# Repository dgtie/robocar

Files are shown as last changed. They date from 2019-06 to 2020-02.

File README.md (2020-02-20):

# robocar
stm32f103c8t6

## Setup SD card
[Download Raspberry Pi Zero WH image](https://polyuit-my.sharepoint.com/:u:/g/personal/ensylam_polyu_edu_hk/EfPde7mzcR5NiaSuWeZethsBixlZN2U6amez3VQq-VrPfw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)\
Write image to SD card. (using balenaEtcher or otherwise)\
Disable SD card reader (through device manager) and then enable it again.\
Modify the following files (in "boot" drive):

- wpa_supplicant.conf (ssid, password)
- hostname & hosts (raspberrypi -> newHostname, eg 19xxxxxxd)

Put SD card to raspberry pi zero and boot.

## SSH to raspberry pi
launch command prompt\
enter "ping -4 19xxxxxxd.local" to check ip address (Bonjour Print Service)\
SSH via putty or otherwise. (ssh pi@19xxxxxxd.local) (pwd = raspberry)

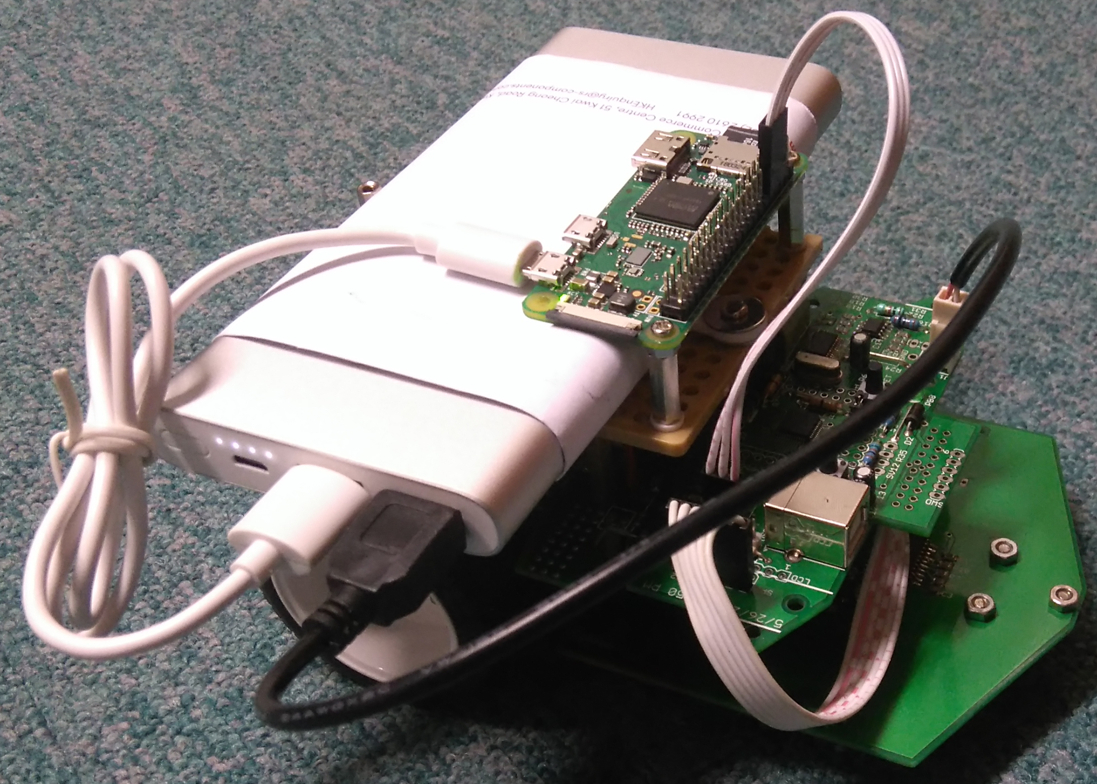
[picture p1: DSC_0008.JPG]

(https://youtu.be/ckLhx3viHC8)

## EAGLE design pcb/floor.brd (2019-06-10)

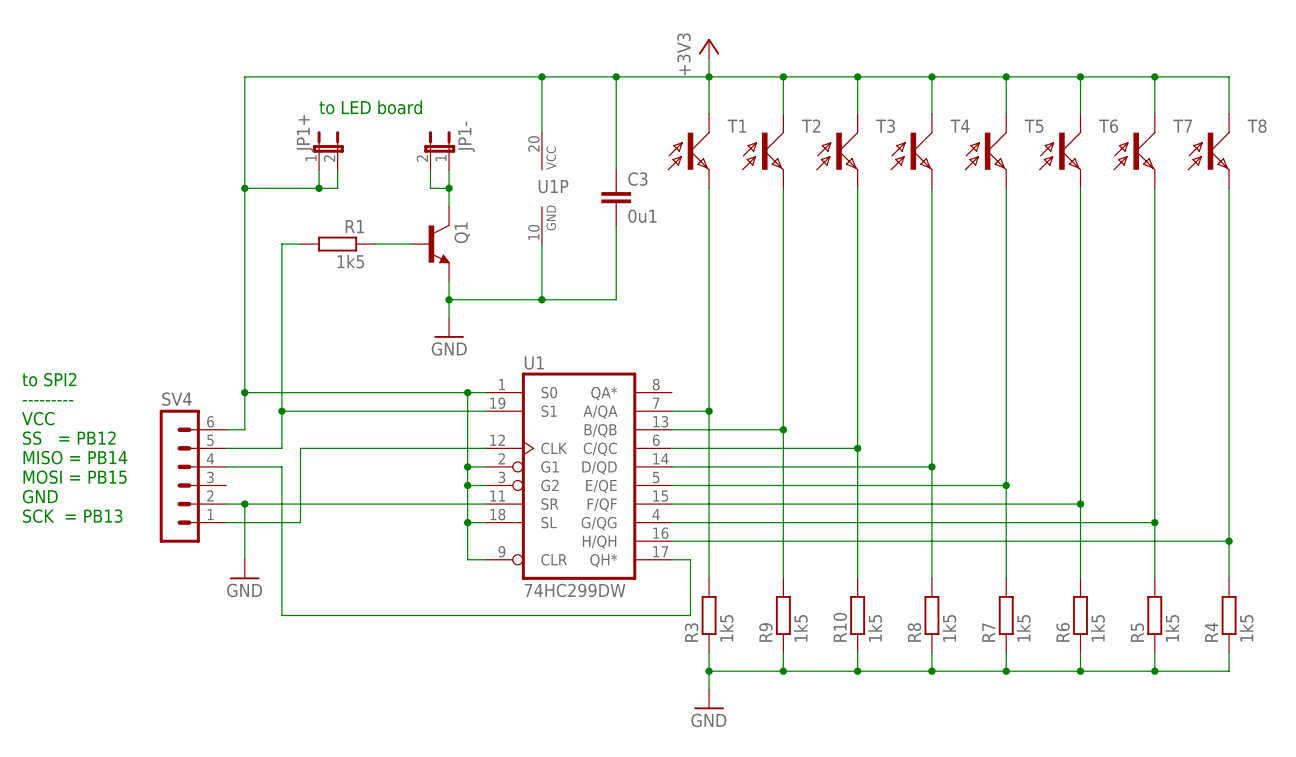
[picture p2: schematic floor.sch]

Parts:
C3: 0u1; C0805
JP1+, JP1-: JP1E; JP1
Q1: BC817-25SMD; SOT23-BEC
R1, R3, R4, R5, R6, R7, R8, R9, R10: 1k5; M0805
SV4: MA06-1
T1, T2, T3, T4, T5, T6, T7, T8: PT17-21B; CHIPLED_0805
U1: 74HC299DW; SO20W

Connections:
+3V3: C3.1, JP1+.1, JP1+.2, SV4.6, T1.C, T2.C, T3.C, T4.C, T5.C, T6.C, T7.C, T8.C, U1.1 (S0), U1.2 (G1), U1.3 (G2), U1.9 (CLR), U1.18 (SL), U1.20 (VCC)
GND: C3.2, Q1.E, R3.1, R4.1, R5.1, R6.1, R7.1, R8.1, R9.1, R10.1, SV4.2, U1.10 (GND), U1.11 (SR)
unnamed: R3.2, T1.A (E), U1.7 (A/QA)
unnamed: JP1-.1, JP1-.2, Q1.C
unnamed: R4.2, T8.A (E), U1.16 (H/QH)
unnamed: R9.2, T2.A (E), U1.13 (B/QB)
unnamed: R10.2, T3.A (E), U1.6 (C/QC)
unnamed: R8.2, T4.A (E), U1.14 (D/QD)
unnamed: R7.2, T5.A (E), U1.5 (E/QE)
unnamed: R6.2, T6.A (E), U1.15 (F/QF)
unnamed: R5.2, T7.A (E), U1.4 (G/QG)
unnamed: SV4.1, U1.12 (CLK)
unnamed: SV4.4, U1.17 (QH*)
unnamed: R1.2, SV4.5, U1.19 (S1)
unnamed: Q1.B, R1.1

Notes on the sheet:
to SPI2 --------- VCC SS = PB12 MISO = PB14 MOSI = PB15 GND SCK = PB13
to LED board

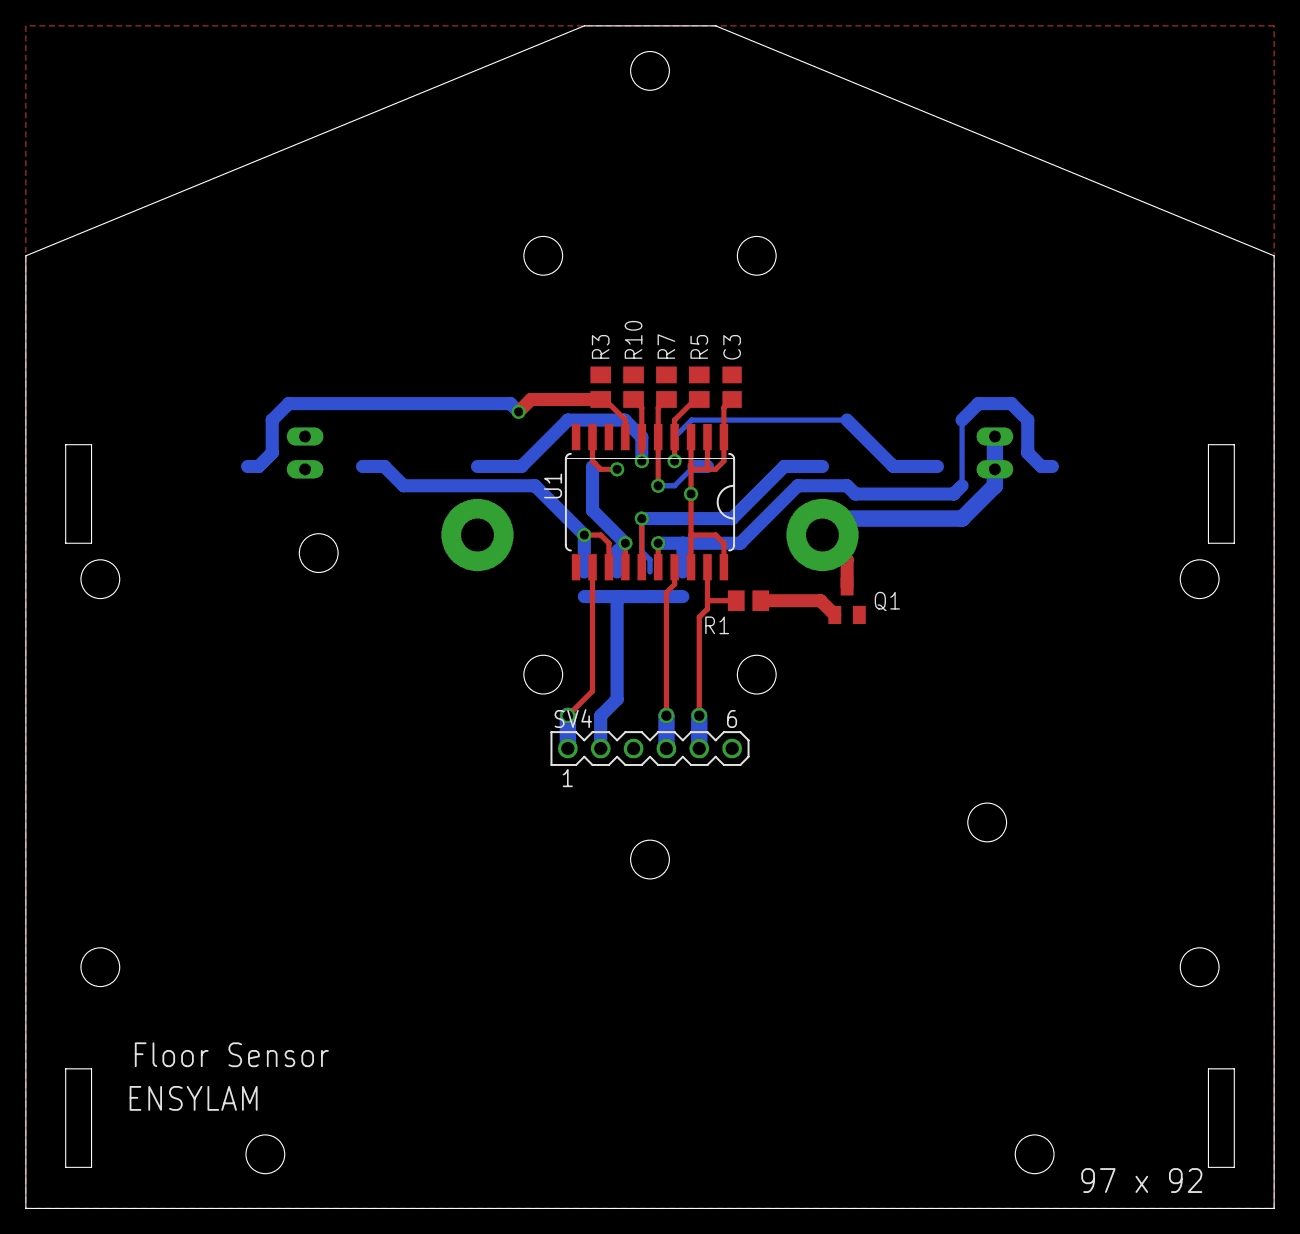
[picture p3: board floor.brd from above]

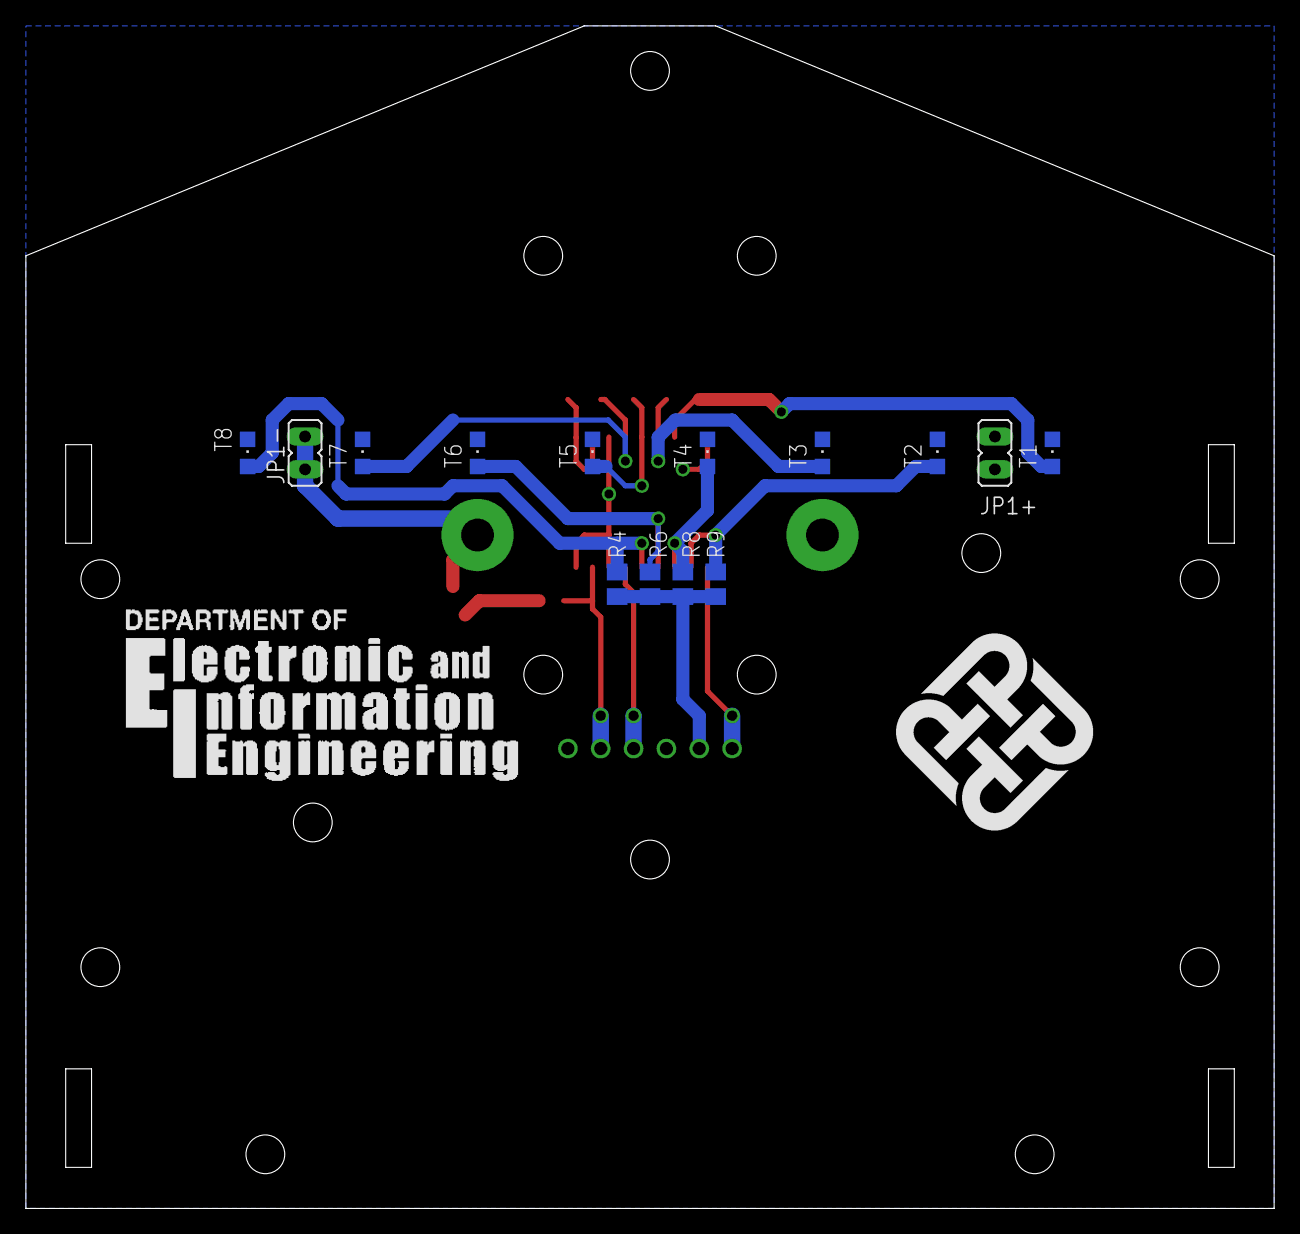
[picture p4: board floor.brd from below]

Board: 2 copper layers, 96.5 x 91.4 mm, 25 parts (16 on the bottom side), 15 nets.

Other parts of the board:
U$1: EIE
U$2: POLYU

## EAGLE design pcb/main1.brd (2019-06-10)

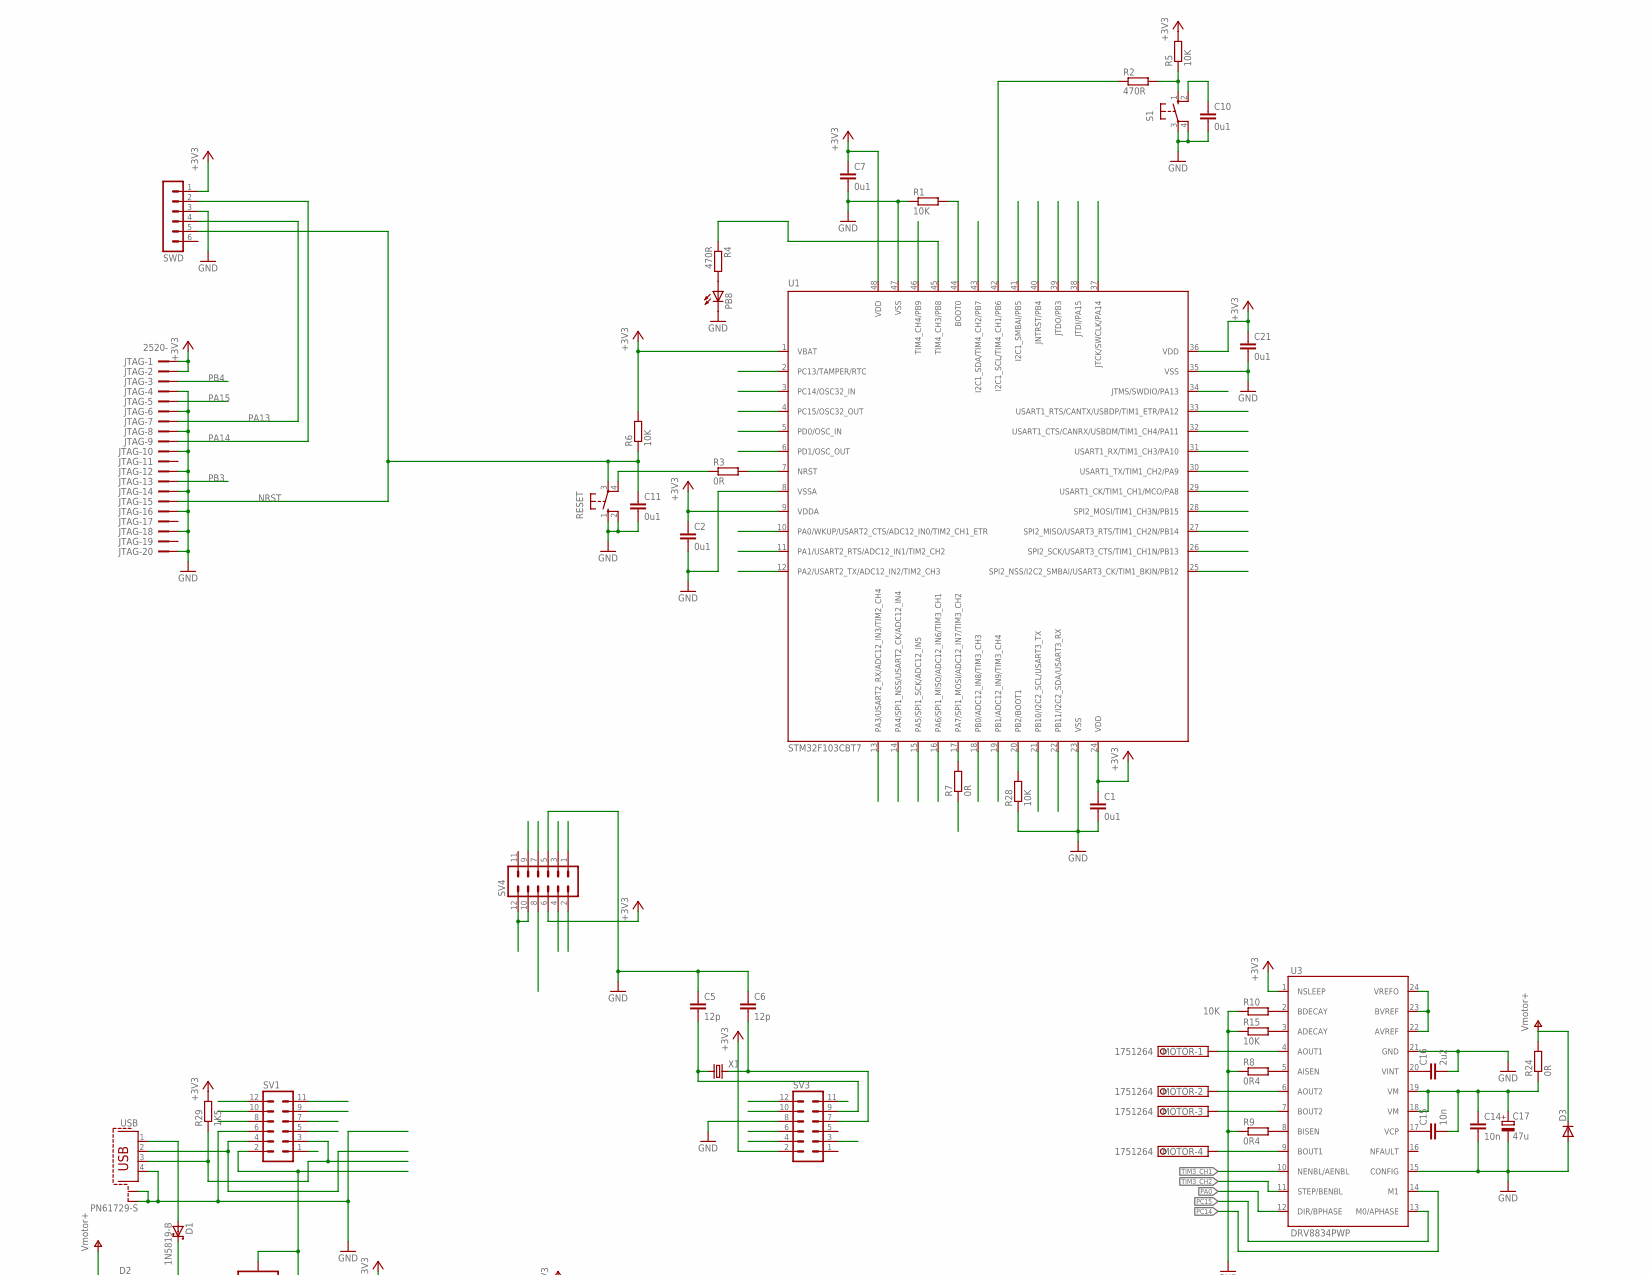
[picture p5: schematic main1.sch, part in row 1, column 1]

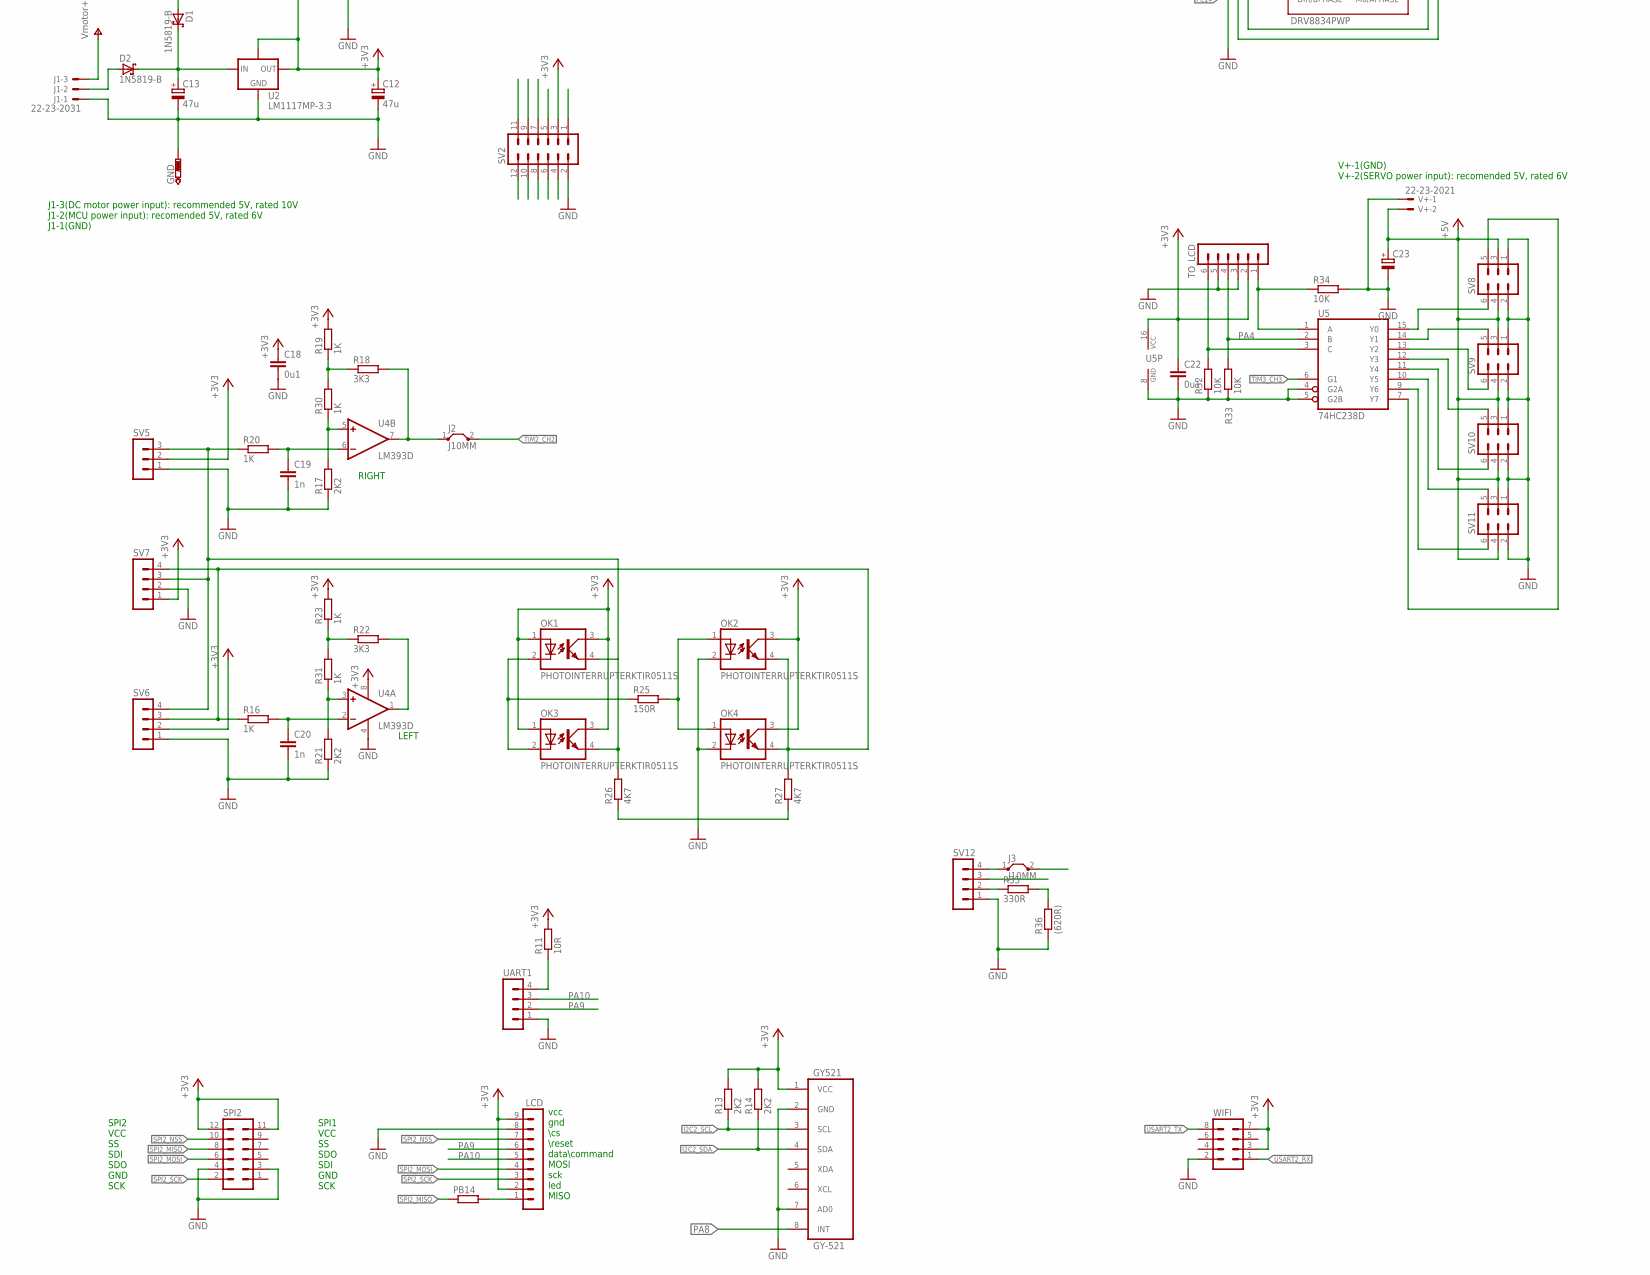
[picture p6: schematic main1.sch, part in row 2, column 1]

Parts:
C1, C2, C7, C10, C11, C18, C21, C22: 0u1; C0805
C5, C6: 12p; C0805
C12, C13, C17: 47u; E1,8-4
C14, C15: 10n; C0805
C16: 2u2; C0805
C19, C20: 1n; C0805
C23: CPOL-EUE2.5-7; E2,5-7
D1, D2: 1N5819-B; DO41-7.6
D3: DIODE-SMB; SMB
GND: PTR1PAD1-13; P1-13
GY521: GY-521
J1: 22-23-2031
J2, J3: J10MM; 10
JTAG: 2520-; PAK100/2500-20
LCD: MA09-1
MOTOR: 1751264
OK1, OK2, OK3, OK4: PHOTOINTERRUPTERKTIR0511S; KTIR0511S
PB8: LED3MM
PB14: R-EU_0207/10; 0207/10
R1, R6, R28, R32, R33, R34: 10K; M0805
R2, R4: 470R; 0207/10
R3, R7, R24: 0R; 0207/10
R5: 10K; 0207/10
R8, R9: 0R4; R2010
R10, R15: 10K; R0805
R11: 10R; M0805
R13, R14, R17, R21: 2K2; M0805
R16, R20: 1K; 0207/10
R18, R22: 3K3; M0805
R19, R23, R30, R31: 1K; M0805
R25: 150R; 0207/10
R26, R27: 4K7; M0805
R29: 1K5; M0805
R35: 330R; M0805
R36: (620R); M0805
RESET: 10-XX; B3F-10XX
S1: 10-XX; B3F-10XX
SPI2: MA06-2
SV1, SV2, SV3, SV4: MA06-2
SV5: MA03-1
SV6, SV7, SV12: MA04-1
SV8, SV9, SV10, SV11: MA03-2
SWD: MA06-1
TO_LCD: MA06-1
U1: STM32F103CBT7; LQFP48-7X7
U2: LM1117MP-3.3; SOT230P700X180-4N
U3: DRV8834PWP; PWP-TSSOP24
U4: LM393D; SO08
U5: 74HC238D; SO16
UART1: MA04-1
USB: PN61729-S
V+: 22-23-2021
WIFI: MA04-2
X1: CRYSTALHC49S; HC49/S

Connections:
+3V3: C1.1, C2.1, C7.1, C12.+, C18.1, C21.1, C22.1, GY521.1 (VCC), JTAG.1, JTAG.2, LCD.2, LCD.9, OK1.1 (A), OK1.3 (COL), OK2.3 (COL), OK3.1 (A), OK3.3 (COL), OK4.3 (COL), R5.2, R6.2, R11.2, R13.2, R14.2, R19.2, R23.2, R29.2, SPI2.11, SPI2.12, SV1.2, SV2.3, SV3.2, SV4.6, SV5.2, SV6.2, SV7.1, SWD.1, TO_LCD.2, U1.1 (VBAT), U1.9 (VDDA), U1.24 (VDD), U1.36 (VDD), U1.48 (VDD), U2.2 (OUT), U2.4 (TAB), U3.1 (NSLEEP), U4.8 (V+), U5.16 (VCC), WIFI.3, WIFI.7
+5V: C23.+, SV8.3, SV8.4, SV9.3, SV9.4, SV10.3, SV10.4, SV11.3, SV11.4, V+.2
BOOT0: R1.2, SV2.5, U1.44 (BOOT0)
BOOT1: R28.2, SV4.8, U1.20 (PB2/BOOT1)
GND: C1.2, C2.2, C5.1, C6.1, C7.2, C10.2, C11.2, C12.-, C13.-, C14.2, C16.2, C17.-, C18.2, C19.2, C20.2, C21.2, C22.2, C23.-, D3.A, GND.TP, GY521.2 (GND), GY521.7 (AD0), J1.1, JTAG.4, JTAG.6, JTAG.8, JTAG.10, JTAG.12, JTAG.14, JTAG.16, JTAG.18, JTAG.20, LCD.8, OK2.2 (C), OK4.2 (C), PB8.K (C), R1.1, R8.1, R9.1, R10.1, R15.1, R17.1, R21.1, R26.1, R27.1, R28.1, R32.1, R33.1, R34.2, R36.1, RESET.1 (S), RESET.2 (S1), S1.3, S1.4 (P1), SPI2.3, SPI2.4, SV1.6, SV2.2, SV3.8, SV4.5, SV5.1, SV6.1, SV7.2, SV8.1, SV8.2, SV9.1, SV9.2, SV10.1, SV10.2, SV11.1, SV11.2, SV12.1, SWD.3, TO_LCD.3, TO_LCD.5, U1.8 (VSSA), U1.23 (VSS), U1.35 (VSS), U1.47 (VSS), U2.1 (GND), U3.15 (CONFIG), U3.21 (GND), U3.EXP (GND), U4.4 (V-), U5.4 (G2A), U5.5 (G2B), U5.8 (GND), UART1.1, USB.4, USB.S1, USB.S2, V+.1, WIFI.2
I2C2_SCL: GY521.3 (SCL), R13.1, SV4.9, U1.21 (PB10/I2C2_SCL/USART3_TX)
I2C2_SDA: GY521.4 (SDA), R14.1, SV4.10, SV4.12, U1.22 (PB11/I2C2_SDA/USART3_RX)
unnamed: OK1.4 (EMIT), OK3.4 (EMIT), R20.1, R26.2, SV5.3, SV6.4, SV7.3
unnamed: D1.A, USB.1
unnamed: J3.1, SV12.4
unnamed: R11.1, UART1.4
unnamed: R3.2, U1.7 (NRST)
unnamed: OK1.2 (C), OK3.2 (C), R25.1
unnamed: R18.1, R19.1, R30.2
unnamed: R22.1, R23.1, R31.2
unnamed: LCD.1, PB14.2
unnamed: OK2.1 (A), OK4.1 (A), R25.2
unnamed: R3.1, RESET.4 (P1)
unnamed: OK2.4 (EMIT), OK4.4 (EMIT), R16.1, R27.2, SV6.3, SV7.4
unnamed: D2.A, J1.2, J3.2
unnamed: SV8.6, U5.15 (Y0)
unnamed: SV9.5, U5.14 (Y1)
unnamed: SV9.6, U5.13 (Y2)
unnamed: SV10.5, U5.12 (Y3)
unnamed: SV10.6, U5.11 (Y4)
unnamed: C19.1, R20.2, U4.6 (-IN)
unnamed: R2.2, R5.1, S1.1 (S)
unnamed: C10.1, S1.2 (S1)
unnamed: SV11.5, U5.10 (Y5)
unnamed: SV11.6, U5.9 (Y6)
unnamed: SV8.5, U5.7 (Y7)
unnamed: C13.+, D1.C, D2.C, U2.3 (IN)
unnamed: PB8.A, R4.2
unnamed: R7.2, U1.17 (PA7/SPI1_MOSI/ADC12_IN7/TIM3_CH2)
unnamed: R35.1, SV12.2
unnamed: R8.2, U3.5 (AISEN)
unnamed: R9.2, U3.8 (BISEN)
unnamed: R10.2, U3.2 (BDECAY)
unnamed: R15.2, U3.3 (ADECAY)
unnamed: U3.22 (AVREF), U3.23 (BVREF), U3.24 (VREFO)
unnamed: C15.1, U3.17 (VCP)
unnamed: C16.1, U3.20 (VINT)
unnamed: R17.2, R30.1, U4.5 (+IN)
unnamed: C20.1, R16.2, U4.2 (-IN)
unnamed: R21.2, R31.1, U4.3 (+IN)
unnamed: C14.1, C15.2, C17.+, R24.1, U3.18 (VM), U3.19 (VM)
NRST: C11.1, JTAG.15, R6.1, RESET.3, SWD.5
PA0: SV3.10, U1.10 (PA0/WKUP/USART2_CTS/ADC12_IN0/TIM2_CH1_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), U3.12 (DIR/BPHASE)
PA4: R33.2, SV4.1, TO_LCD.4, U1.14 (PA4/SPI1_NSS/USART2_CK/ADC12_IN4), U5.2 (B)
PA5: SV4.2, U1.15 (PA5/SPI1_SCK/ADC12_IN5)
PA8: GY521.8 (INT), SV1.7, U1.29 (USART1_CK/TIM1_CH1/MCO/PA8)
PA9: LCD.6, SV1.8, U1.30 (USART1_TX/TIM1_CH2/PA9), UART1.2
PA10: LCD.5, SV1.5, U1.31 (USART1_RX/TIM1_CH3/PA10), UART1.3
PA13: JTAG.7, SV1.1, SWD.4, U1.34 (JTMS/SWDIO/PA13)
PA14: JTAG.9, SV2.12, SWD.2, U1.37 (JTCK/SWCLK/PA14)
PA15: JTAG.5, SV2.11, U1.38 (JTDI/PA15)
PB1: SV4.7, U1.19 (PB1/ADC12_IN9/TIM3_CH4)
PB3: JTAG.13, SV2.10, U1.39 (JTDO/PB3)
PB4: JTAG.3, R35.2, R36.2, SV2.9, U1.40 (JNTRST/PB4)
PB5: SV2.8, SV12.3, U1.41 (I2C1_SMBAI/PB5)
PB6: R2.1, SV2.7, U1.42 (I2C1_SCL/TIM4_CH1/PB6)
PB7: R22.2, SV2.6, U1.43 (I2C1_SDA/TIM4_CH2/PB7), U4.1 (OUT)
PB8: R4.1, SV2.4, U1.45 (TIM4_CH3/PB8)
PC13: SV3.4, U1.2 (PC13/TAMPER/RTC)
PC14: SV3.3, U1.3 (PC14/OSC32_IN), U3.14 (M1)
PC15: SV3.6, U1.4 (PC15/OSC32_OUT), U3.13 (M0/APHASE)
PD0: C6.2, SV3.7, U1.5 (PD0/OSC_IN), X1.2
PD1: C5.2, SV3.9, U1.6 (PD1/OSC_OUT), X1.1
SPI2_MISO: PB14.1, SPI2.8, SV1.9, U1.27 (SPI2_MISO/USART3_RTS/TIM1_CH2N/PB14)
SPI2_MOSI: LCD.4, SPI2.6, SV1.10, U1.28 (SPI2_MOSI/TIM1_CH3N/PB15)
SPI2_NSS: LCD.7, SPI2.10, SV1.11, U1.25 (SPI2_NSS/I2C2_SMBAI/USART3_CK/TIM1_BKIN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)
SPI2_SCK: LCD.3, SPI2.2, SV1.12, U1.26 (SPI2_SCK/USART3_CTS/TIM1_CH1N/PB13)
TIM2_CH2: J2.2, SV3.12, U1.11 (PA1/USART2_RTS/ADC12_IN1/TIM2_CH2)
TIM2_CH2A: J2.1, R18.2, U4.7 (OUT)
TIM3_CH1: SV4.3, U1.16 (PA6/SPI1_MISO/ADC12_IN6/TIM3_CH1), U3.10 (NENBL/AENBL)
TIM3_CH2: R7.1, SV3.11, U3.11 (STEP/BENBL)
TIM3_CH3: SV4.4, U1.18 (PB0/ADC12_IN8/TIM3_CH3), U5.6 (G1)
TIM4_CH4: SV2.1, U1.46 (TIM4_CH4/PB9)
U5A: R34.1, TO_LCD.1, U5.1 (A)
U5C: R32.2, TO_LCD.6, U5.3 (C)
USART2_RX: U1.13 (PA3/USART2_RX/ADC12_IN3/TIM2_CH4), WIFI.1
USART2_TX: U1.12 (PA2/USART2_TX/ADC12_IN2/TIM2_CH3), WIFI.8
USBDM: SV1.4, U1.32 (USART1_CTS/CANRX/USBDM/TIM1_CH4/PA11), USB.2
USBDP: R29.1, SV1.3, U1.33 (USART1_RTS/CANTX/USBDP/TIM1_ETR/PA12), USB.3
V+: D3.C, J1.3, R24.2
X21: MOTOR.4, U3.9 (BOUT1)
X22: MOTOR.3, U3.7 (BOUT2)
X23: MOTOR.2, U3.6 (AOUT2)
X24: MOTOR.1, U3.4 (AOUT1)

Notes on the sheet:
SPI2 VCC SS SDI SDO GND SCK
vcc gnd \cs \reset data\command MOSI sck led MISO
RIGHT
LEFT
SPI1 VCC SS SDO SDI GND SCK
J1-3(DC motor power input): recommended 5V, rated 10V J1-2(MCU power input): recomended 5V, rated 6V J1-1(GND)
V+-1(GND) V+-2(SERVO power input): recomended 5V, rated 6V

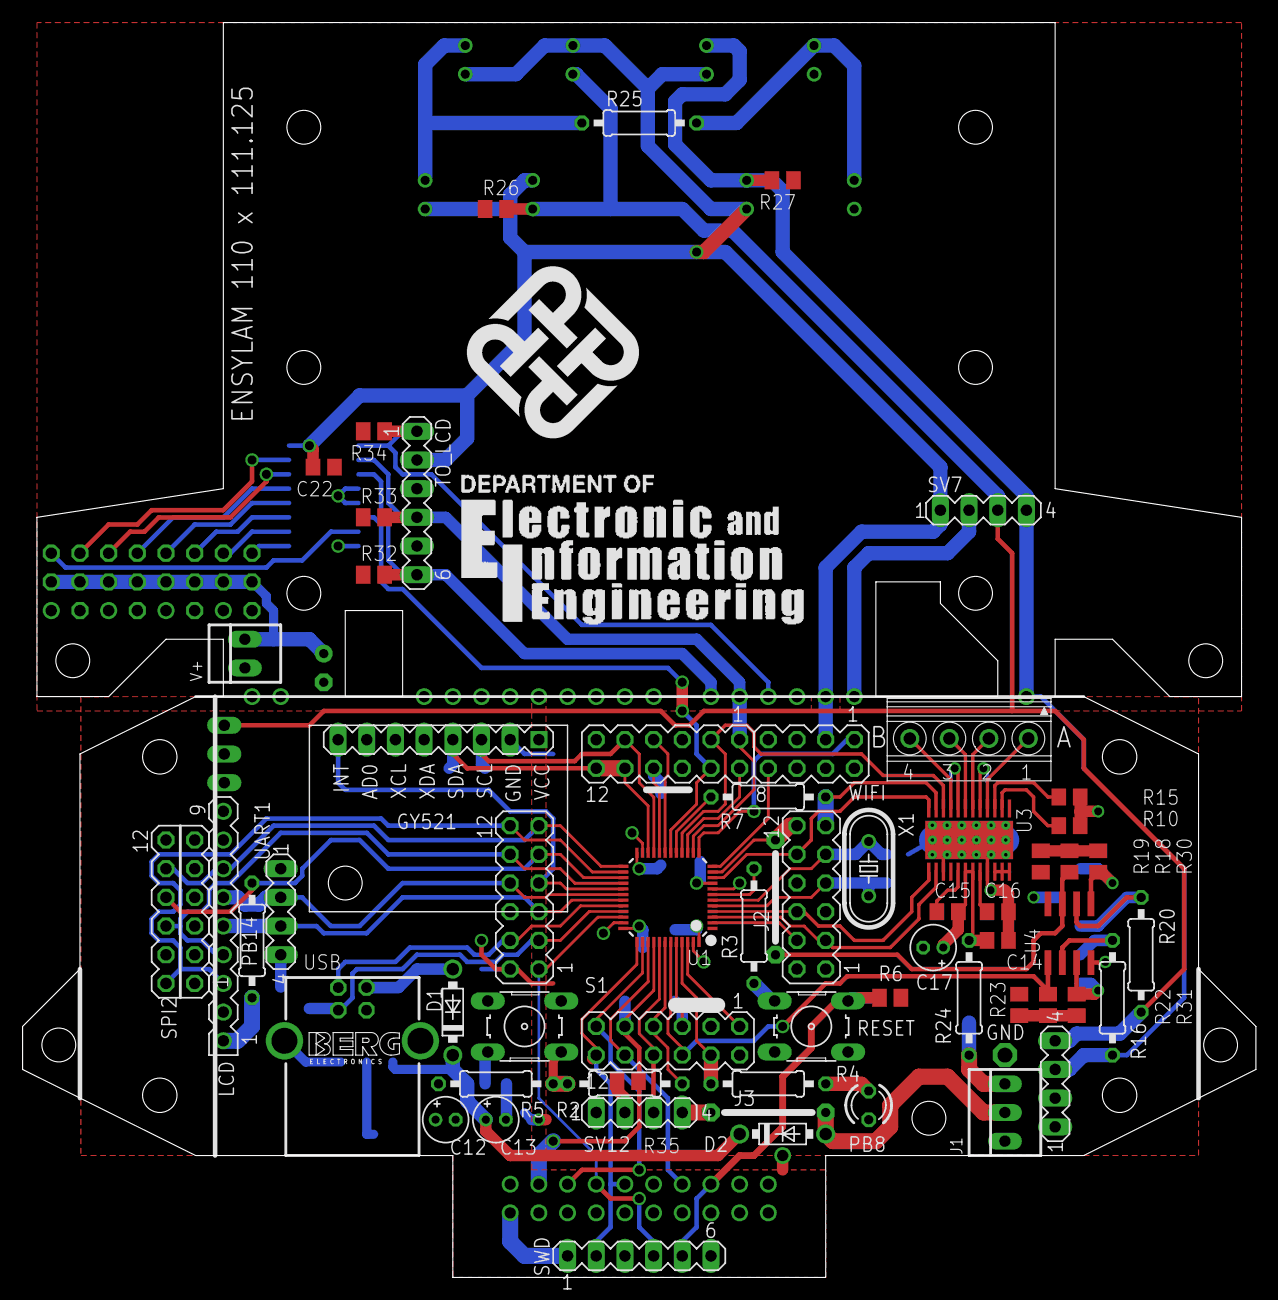
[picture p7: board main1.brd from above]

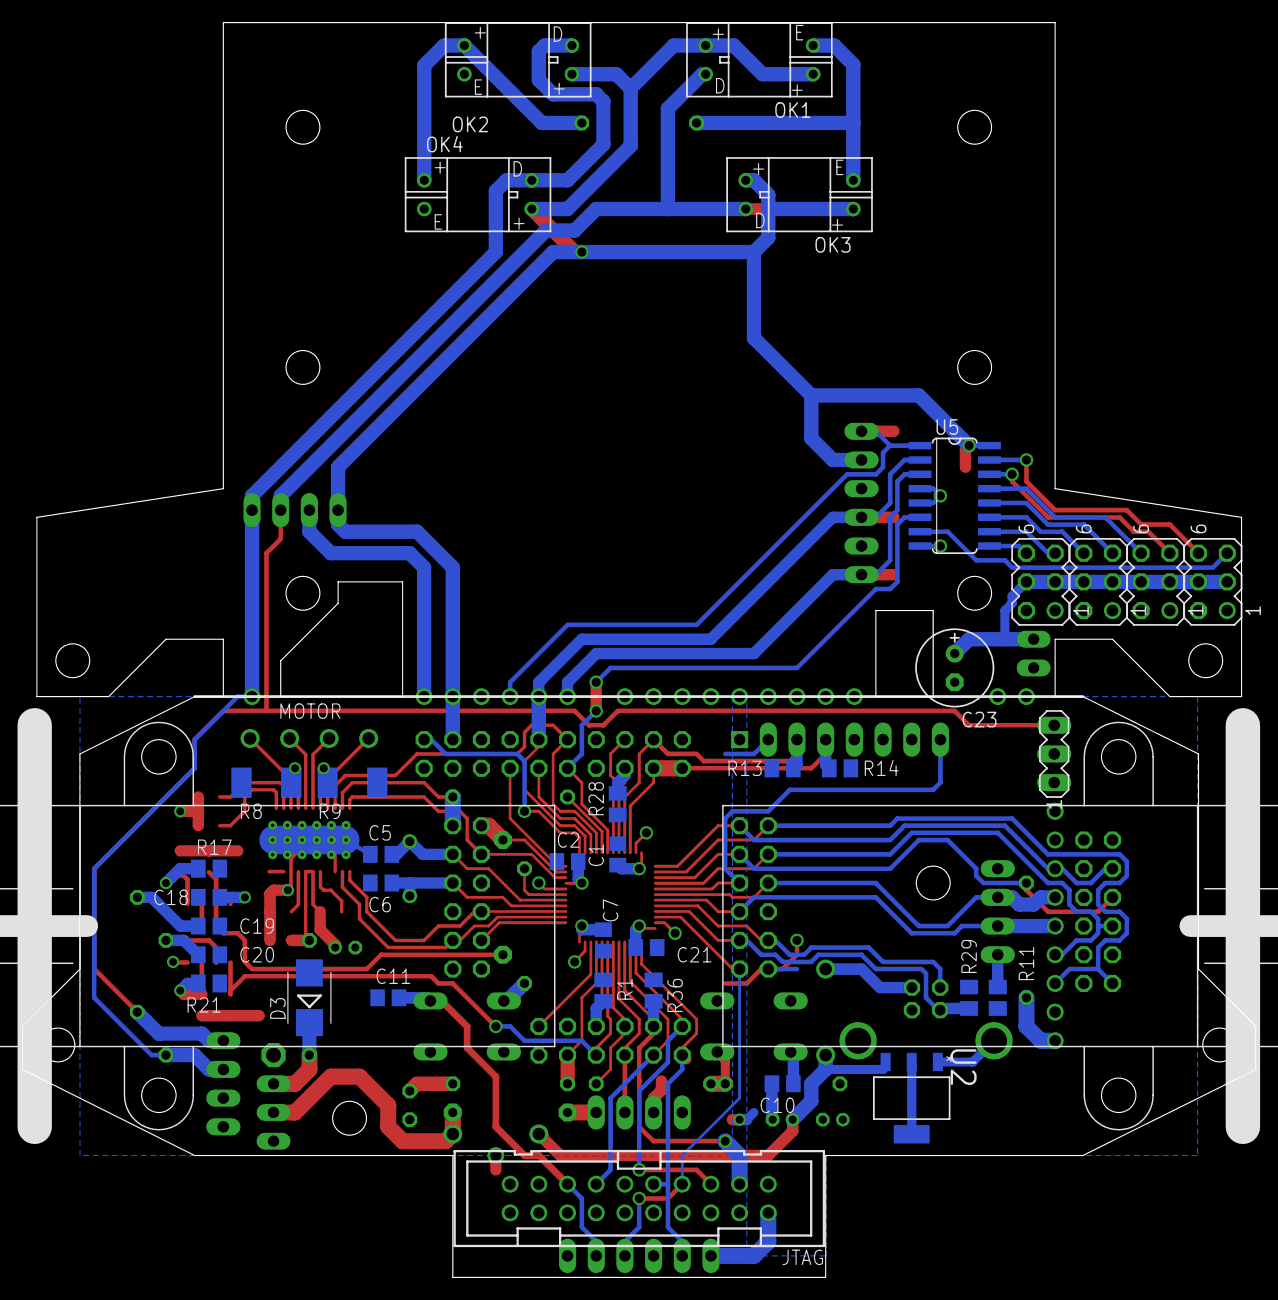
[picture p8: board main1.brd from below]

Board: 2 copper layers, 109.2 x 111.1 mm, 102 parts (38 on the bottom side), 89 nets.

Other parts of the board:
U$1: POLYU
U$2: EIE
U$5, U$6: 70103

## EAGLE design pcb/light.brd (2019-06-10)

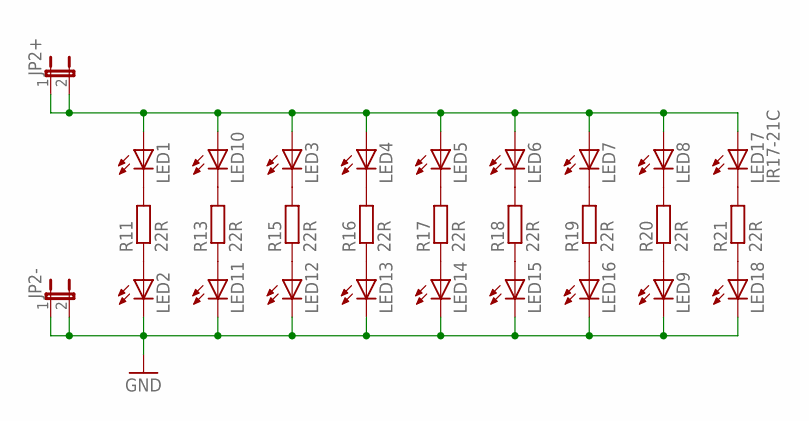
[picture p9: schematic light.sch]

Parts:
JP2+, JP2-: JP1E; JP1
LED1, LED2, LED3, LED4, LED5, LED6, LED7, LED8, LED9, LED10, LED11, LED12, LED13, LED14, LED15, LED16, LED18: LEDCHIPLED_0805; CHIPLED_0805
LED17: IR17-21C; CHIPLED_0805
R11, R13, R15, R16, R17, R18, R19, R20, R21: 22R; M0805

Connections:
+3V3: JP2+.1, JP2+.2, LED1.A, LED3.A, LED4.A, LED5.A, LED6.A, LED7.A, LED8.A, LED10.A, LED17.A
GND: JP2-.1, JP2-.2, LED2.C, LED9.C, LED11.C, LED12.C, LED13.C, LED14.C, LED15.C, LED16.C, LED18.C
unnamed: LED2.A, R11.1
unnamed: LED1.C, R11.2
unnamed: LED10.C, R13.2
unnamed: LED11.A, R13.1
unnamed: LED3.C, R15.2
unnamed: LED4.C, R16.2
unnamed: LED5.C, R17.2
unnamed: LED6.C, R18.2
unnamed: LED7.C, R19.2
unnamed: LED8.C, R20.2
unnamed: LED9.A, R20.1
unnamed: LED12.A, R15.1
unnamed: LED13.A, R16.1
unnamed: LED14.A, R17.1
unnamed: LED15.A, R18.1
unnamed: LED16.A, R19.1
unnamed: LED18.A, R21.1
unnamed: LED17.C, R21.2

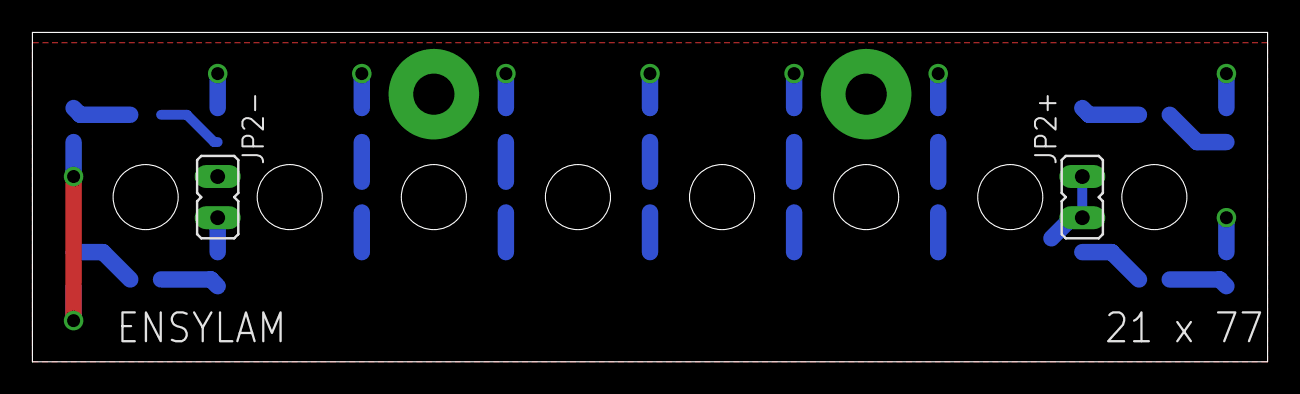
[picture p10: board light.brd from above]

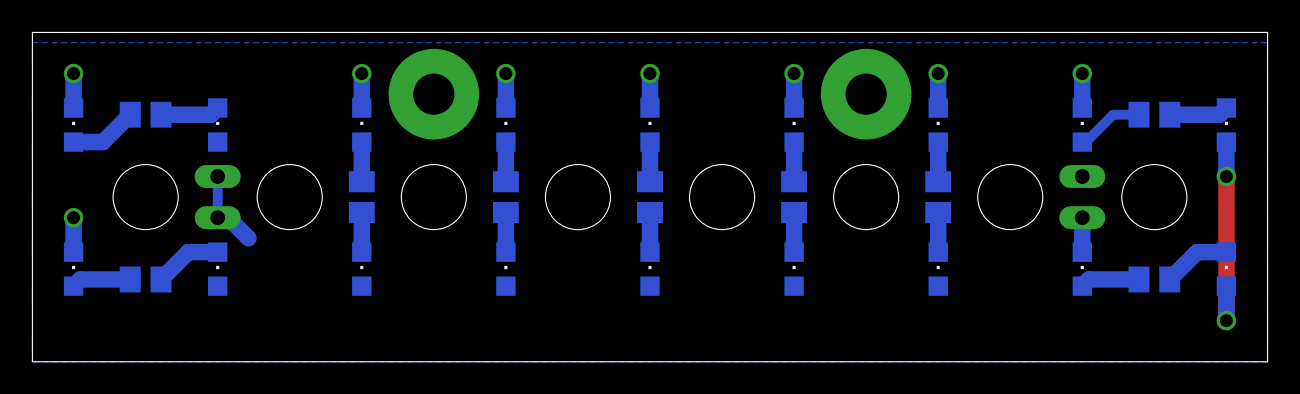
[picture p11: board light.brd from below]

Board: 2 copper layers, 76.2 x 20.3 mm, 29 parts (27 on the bottom side), 20 nets.

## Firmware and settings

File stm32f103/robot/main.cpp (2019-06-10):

#include "led.h"
#include "usart1.h"
#include "wheel.h"
#include "i2cm.h"
#include <lamos.h>

char b[2];

int main(void) {
  user::wait(200);
  if (user::i2cmWrite(60, 2, b)) led_on();
  while(1);
}

int x = 0x12345678;

//void on_button_down(void) { x++; usart1_tx((char*)&x, 4); }
void on_button_down(void) {
  b[1] ^= 10;
  led_toggle();
  i2cm_write(60, 2, b);
}

int zero = 0;
int one = -1;

void usart1_receive(char c) {
  if (c == 'n') led_on();
  if (c == 't') led_toggle();
  if (c == 'x') usart1_tx((char*)&x, sizeof(x));
  if (c == 'y') usart1_tx((char*)&zero, sizeof(x));
  if (c == 'z') usart1_tx((char*)&one, sizeof(x));
  if (c == 'f') wheel(FORWARD);
  if (c == 'b') wheel(BACKWARD);
  if (c == 'l') wheel(LEFT);
  if (c == 'r') wheel(RIGHT);
  if (c == 's') wheel(STOP);
}

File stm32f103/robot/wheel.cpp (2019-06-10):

#include <stm32f10x.h>
#include <lamos.h>
#include "wheel.h"

/*
PA1 = TIM2_CH2, PB7 = TIM4_CH2

PA6 = TIM3_CH1 = AENBL
PA7 = TIM3_CH2 = BENBL
PA0 = BPHASE
PC15 = APHASE
PC14 = M1

PB12 = IR LED / MODE
PB13 = SPI2_SCK
PB14 = SPI2_MISO
PB15 = SPI2_MOSI
*/

#define PERIOD 44999	// period = 2.5 ms (400 Hz)

void __attribute__((weak)) wheel(wheel_struct &p) { p.left = p.right = 0; }

namespace
{

wheel_mode mode = FORWARD;

}

void wheel(wheel_mode m) {
  switch (mode = m) {
  case FORWARD:
    GPIOA->BRR = 1; GPIOC->BRR = 0x8000;
    break;
  case BACKWARD:
    GPIOA->BSRR = 1; GPIOC->BSRR = 0x8000;
    break;
  case LEFT:
    GPIOA->BSRR = 1; GPIOC->BRR = 0x8000;
    break;
  case RIGHT:
    GPIOA->BRR = 1; GPIOC->BSRR = 0x8000;
    break;
  default:;
  }
}

namespace
{

wheel_struct val;
struct {unsigned short left, right;} last, current;

SERVICE constructor(void) {
  RCC->APB1ENR |= RCC_APB1ENR_TIM2EN | RCC_APB1ENR_TIM3EN | RCC_APB1ENR_TIM4EN;
  TIM3->PSC = 3;			// 72/4 = 18 MHz
  TIM3->ARR = PERIOD;
  TIM2->SMCR = TIM4->SMCR = 0x67;	// TI2FP2
  TIM2->CCMR1 |= 0x100;			// CC2 as input, IC2 mapped on TI2
  TIM4->CCMR1 |= 0x100;
  TIM2->CR1 |= TIM_CR1_CEN;
  TIM4->CR1 |= TIM_CR1_CEN;

  RCC->APB2ENR |= RCC_APB2ENR_IOPAEN | RCC_APB2ENR_IOPCEN;
  int
  i = GPIOA->CRL & 0x00fffff0;		// select PA7, PA6, & PA0
  GPIOA->CRL = i | 0xaa000002;		// a = AFPP, 2 = PP(2MHz)
  i = GPIOC->CRH & 0x00ffffff;		// select PC15 & PC14
  GPIOC->CRH = i | 0x22000000;		// 2 = PP(2MHz)
  TIM3->CCMR1 = 0x6868;				// ch2 & ch1: PWM1, preload
  TIM3->CCER = TIM_CCER_CC2E | TIM_CCER_CC1E;	// OC output enable

  RCC->APB2ENR |= RCC_APB2ENR_IOPBEN;		// enable clock for PORTB
  i = GPIOB->CRH & 0xff00ffff;			// select PB13, PB12
  GPIOB->CRH = i | 0x00a20000;			// a = AFPP, 2 = PP 2MHz
  RCC->APB1ENR |= RCC_APB1ENR_SPI2EN;		// power up SPI2
  SPI2->CR2 |= SPI_CR2_RXNEIE;
  SPI2->CR1 = SPI_CR1_CPHA | SPI_CR1_CPOL | SPI_CR1_MSTR | SPI_CR1_BR |
              SPI_CR1_SSM | SPI_CR1_SSI;
						// 36 MHz / 256 = 140.625 kHz
  SPI2->CR1 |= SPI_CR1_SPE;

  TIM3->CR1 |= TIM_CR1_CEN;		// turn on timer
  TIM3->SR &= ~TIM_SR_UIF;		// clear UIF
  TIM3->DIER |= TIM_DIER_UIE;		// update interrupt enable
  NVIC_EnableIRQ(TIM3_IRQn);

  last.right = TIM2->CNT;
  last.left = TIM4->CNT;

  return [](Service&) {
    if (mode == STOP) { TIM3->CCR1 = TIM3->CCR2 = 0; return; }
    val.left = current.left - last.left; last.left = current.left;
    val.right = current.right - last.right; last.right = current.right;
    wheel(val);
    TIM3->CCR2 = val.left > PERIOD ? PERIOD : val.left;
    TIM3->CCR1 = val.right > PERIOD ? PERIOD : val.right;
  };
}

Service _wheel(constructor());

}

extern "C"
{

void TIM3_IRQHandler(void) {
  current.right = TIM2->CNT;
  current.left = TIM4->CNT;
  val.floor = 0xffffffff;
  GPIOB->BSRR = 0x1000;			// IR LED ON, MODE = parallel load
  SPI2->DR = 0;
  NVIC_EnableIRQ(SPI2_IRQn);
  TIM3->SR &= ~TIM_SR_UIF;
}

void SPI2_IRQHandler(void) {
  char *c = (char*)&val.floor;
  *c = SPI2->DR;
  if (GPIOB->ODR & 0x1000) {
    if (!(val.floor>>=8)) GPIOB->BRR = 0x1000;
    SPI2->DR = 0;
  } else {
    NVIC_DisableIRQ(SPI2_IRQn);
    _wheel.append(0);
  }
}

}
